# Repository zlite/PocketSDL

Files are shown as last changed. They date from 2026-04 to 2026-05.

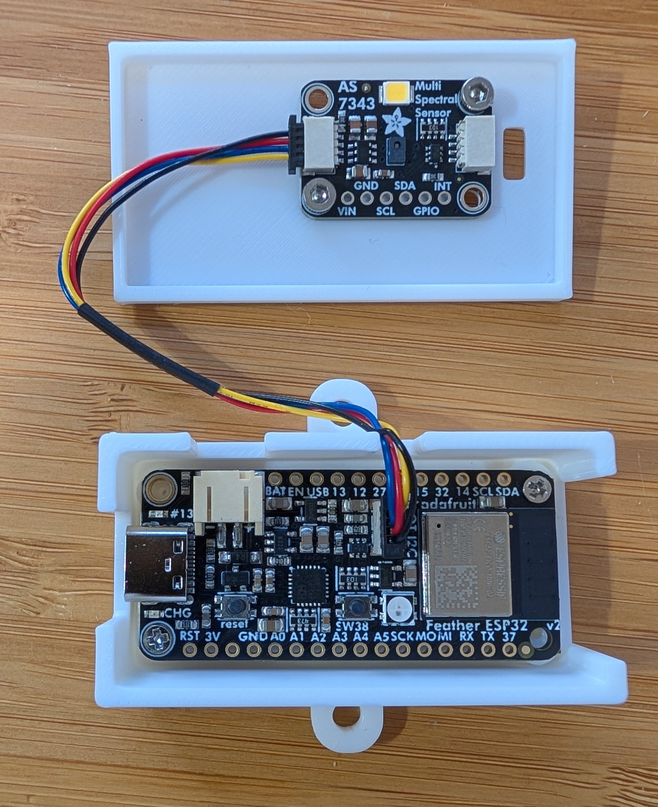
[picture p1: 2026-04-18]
PXL_20260418_005741949.jpg

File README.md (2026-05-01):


This is a minimal self-driving lab demonstration to "discover" color theory by doing an exploration/exploitation search of color space by driving a RGB LED and measuring it with a color sensor, which can be made for $40. Has an optional battery box at the bottom for a 200mah LiPo battery that the Feather can automatically recharge, making this a totally self-contained and portable SDL.

Load code onto ESP32 with the Platormio extension in VSCode (change the port in the ini file to whatever your ESP32 shows up as). Codex or Claude Code extensions in VS Code will do this for you. If you haven't set your wifi details in the code, it will prompt you to enter them on the serial terminal (115200 baud) and then save them so you don't have to do it again. Once it's connected to your network, you should be able to open the UI in your web browser by just typing "sdl.local" in the URL bar. 

If it can't find your network or you haven't given it your network details, after 30 seconds it will switch into AP mode and create its own Wifi network called "SDL" (no password). Just connect to that network with your phone or computer and open a browser and the web interface will just show up automagically.

Alternatively, you can just load the file on the ESP32 using the Arduino IDE.

insides
----
flashing

BOM:
- [Adafruit Feather ESP32 V2](https://www.adafruit.com/product/5400)
- [Adafruit 10-channel color sensor](https://www.adafruit.com/product/4698)

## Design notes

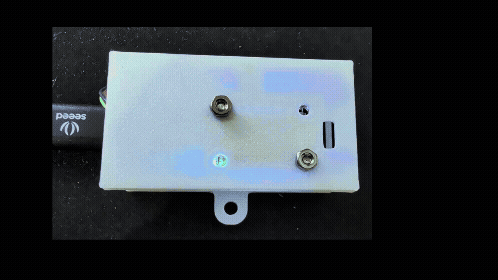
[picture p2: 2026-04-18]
Adobe Express - Video Project.gif

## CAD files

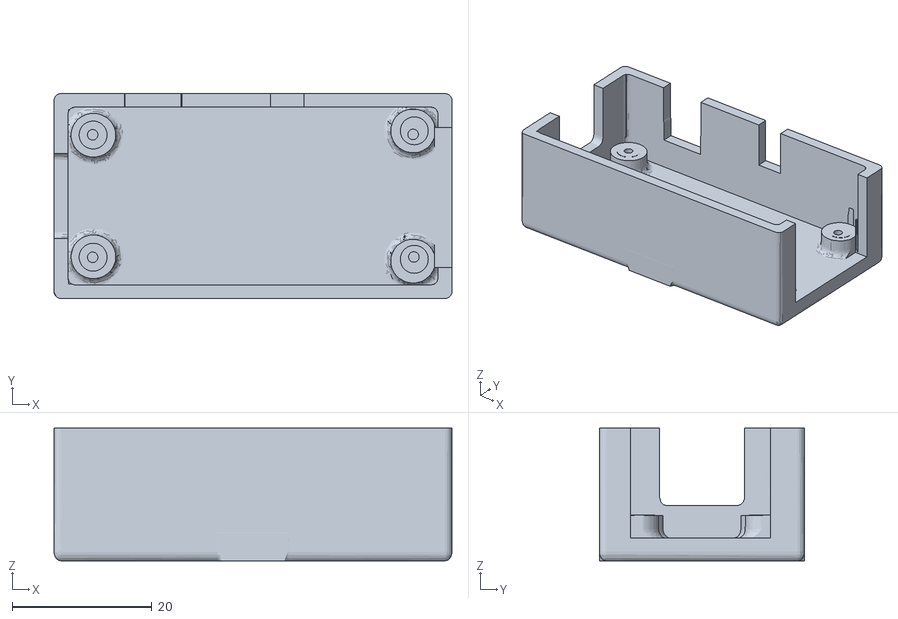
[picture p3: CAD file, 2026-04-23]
base.stl
57.0 x 29.4 x 19.0

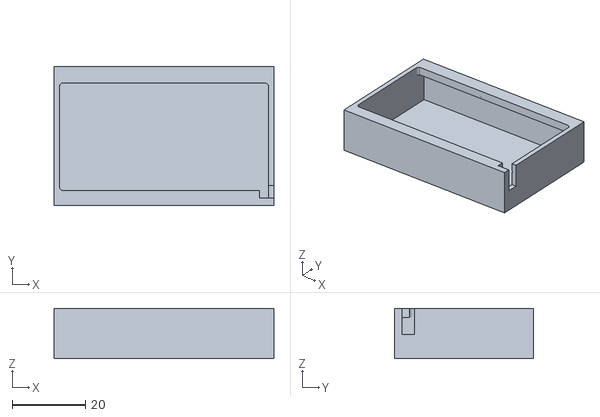
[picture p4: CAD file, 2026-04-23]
batterybox.stl
60.0 x 38.0 x 13.7

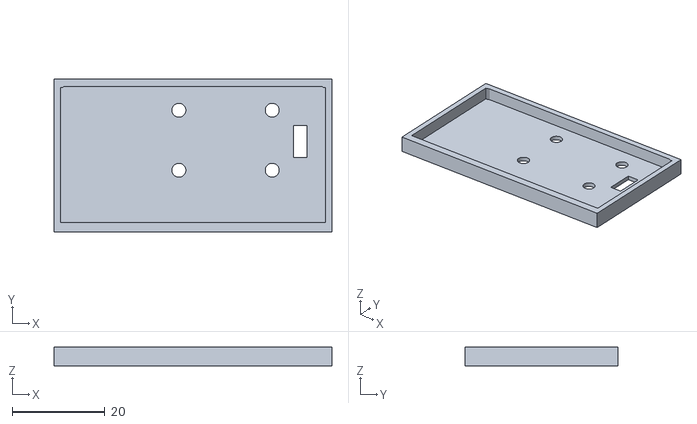
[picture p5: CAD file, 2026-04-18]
cover.stl
60.0 x 33.0 x 4.00

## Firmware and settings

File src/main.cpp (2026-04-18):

#include <Arduino.h>
#include <WiFi.h>
#include <AsyncTCP.h>
#include <ESPAsyncWebServer.h>
#include <ESPmDNS.h>
#include <Wire.h>
#include <math.h>
#include <Preferences.h>
#include <Adafruit_NeoPixel.h>
#include <Adafruit_AS7343.h>

// ── Hardware ──────────────────────────────────────────────────────────────────
#define NEOPIXEL_PIN   0
#define NEOPIXEL_POWER 2
#define LED_BRIGHTNESS 200

#ifndef WIFI_SSID
#define WIFI_SSID "YOUR_WIFI_SSID"
#endif

#ifndef WIFI_PASS
#define WIFI_PASS "YOUR_WIFI_PASSWORD"
#endif

static const char WIFI_SSID_VALUE[] = WIFI_SSID;
static const char WIFI_PASS_VALUE[] = WIFI_PASS;

Adafruit_NeoPixel pixel(1, NEOPIXEL_PIN, NEO_GRB + NEO_KHZ800);
Adafruit_AS7343   as7343;
AsyncWebServer    server(80);
Preferences       prefs;

static uint8_t ledR=0, ledG=0, ledB=0;
static bool    sensorOK=false;
static String  wifiSSID;
static String  wifiPass;

void setLED(uint8_t r, uint8_t g, uint8_t b){
  ledR=r; ledG=g; ledB=b;
  pixel.setPixelColor(0, pixel.Color(r,g,b)); pixel.show();
}

// ── Channel layout (18-ch mode) ───────────────────────────────────────────────
//  0:FZ/450  1:FY/555  2:FXL/600  3:NIR/855  4,5:CLR0
//  6:F2/425  7:F3/475  8:F4/515   9:F6/640   10,11:CLR1
// 12:F1/405 13:F7/690 14:F8/745  15:F5/550   16,17:CLR2
#define NUM_CH 18
static const int   SPEC_CH[] = {12,6,0,7,8,15,1,2,9,13};
static const int   N_SPEC    = 10;
static const float SPEC_WL[] = {405,425,450,475,515,550,555,600,640,690};

// LED spectral weights (Gaussian, R~635nm G~528nm B~455nm)
static const float W_R[NUM_CH]={0.00f,0.11f,0.68f,0.00f,0,0,0.00f,0.00f,0.00f,1.00f,0,0,0.00f,0.39f,0.02f,0.10f,0,0};
static const float W_G[NUM_CH]={0.08f,0.74f,0.12f,0.00f,0,0,0.01f,0.32f,0.93f,0.01f,0,0,0.00f,0.00f,0.00f,0.82f,0,0};
static const float W_B[NUM_CH]={0.98f,0.01f,0.00f,0.00f,0,0,0.49f,0.73f,0.06f,0.00f,0,0,0.14f,0.00f,0.00f,0.01f,0,0};

// ── Buffers ───────────────────────────────────────────────────────────────────
struct Reading { uint8_t r,g,b; uint16_t ch[NUM_CH]; };
static const int LOG_MAX=120; static Reading logBuf[LOG_MAX];
static int logHead=0, logCount=0;

struct Thought { uint8_t r,g,b; float score; bool improved; char msg[96]; };
static const int TH_MAX=50; static Thought thBuf[TH_MAX];
static int thHead=0, thCount=0;

static const int SCORE_MAX=200; static float scoreHist[SCORE_MAX];
static float acceptedScoreHist[SCORE_MAX];
static int scoreHead=0, scoreLen=0;
static int sensorReadFailures=0;

static String jsonEscape(const char* src);
static void setStateMessage(const char* msg);
static void stopExperiment(const char* msg, bool turnLedOff);
static bool hasCompileTimeWiFiCreds();
static bool loadStoredWiFiCreds();
static bool saveStoredWiFiCreds(const String& ssid, const String& pass);
static String readSerialLine(bool echoInput = true);
static bool promptForWiFiCreds();
static void connectWiFi();
static void startMdns();
static bool parseJsonFloat(const String& body, const char* key, float& valueOut);
static String buildStatusJson();
static String buildScoresJson();
static String buildThoughtsJson();
static String buildLogJson();
static String buildSnapshotJson(bool includeLog);
static bool getRequestInt(AsyncWebServerRequest* request, const char* key, int& valueOut);
static bool getRequestFloat(AsyncWebServerRequest* request, const char* key, float& valueOut);
static bool getRequestString(AsyncWebServerRequest* request, const char* key, String& valueOut);
static bool getRequestRgb(AsyncWebServerRequest* request, uint8_t& r, uint8_t& g, uint8_t& b);

void pushScore(float s){
  int idx=scoreHead%SCORE_MAX;
  scoreHist[idx]=s;
  acceptedScoreHist[idx]=-1.0f;
  scoreHead++;
  if(scoreLen<SCORE_MAX)scoreLen++;
}
void pushAcceptedScore(float s){
  int idx=(scoreHead-1+SCORE_MAX)%SCORE_MAX;
  acceptedScoreHist[idx]=s;
}

void addThought(uint8_t r,uint8_t g,uint8_t b,float sc,bool imp,const char* msg){
  Thought& t=thBuf[thHead%TH_MAX]; t.r=r;t.g=g;t.b=b;t.score=sc;t.improved=imp;
  strncpy(t.msg,msg,95); t.msg[95]='\0'; thHead++; if(thCount<TH_MAX)thCount++;
  Serial.printf("[SDL] %s\n",msg);
}

// ── Spectral helpers ──────────────────────────────────────────────────────────
static float recTgtSpec[NUM_CH]={};   // raw target spectrum (sum-normalised in scoring)
static float ambSpec[NUM_CH]={};      // unused — kept for future reference
static uint8_t recTgtR=255, recTgtG=165, recTgtB=0;

static bool isSaturated(const uint16_t* buf){
  for(int i=0;i<N_SPEC;i++) if(buf[SPEC_CH[i]]>60000) return true;
  return false;
}

// Score: 1 - L2 distance between sum-normalised spectra (probability distributions).
// Ambient (dark frame) is subtracted before normalisation so room light doesn't corrupt shape.
// sqrtf(l2) ranges 0 (identical shape) to sqrt(2) (orthogonal), mapped to 0–100%.
float computeScore(const uint16_t* meas){
  if(isSaturated(meas)) return 0.0f;
  float m[N_SPEC], t[N_SPEC];
  float msum=0, tsum=0;
  for(int i=0;i<N_SPEC;i++){
    int ci=SPEC_CH[i];
    m[i]=max(0.0f,(float)meas[ci]-ambSpec[ci]);
    t[i]=recTgtSpec[ci];
    msum+=m[i]; tsum+=t[i];
  }
  if(msum<1.0f||tsum<1.0f) return 0.0f;
  // Luminance penalty: a dim colour that has the right hue shape still scores low.
  // sqrtf keeps it gentle — 50% brightness → 71% penalty, 25% → 50%.
  float lumPenalty = msum < tsum ? sqrtf(msum/tsum) : 1.0f;
  float l2=0;
  for(int i=0;i<N_SPEC;i++){
    float diff=m[i]/msum - t[i]/tsum;
    l2+=diff*diff;
  }
  // Denominator 0.45 calibrated so a random colour averages ~50%; a true match scores ~90%+.
  return max(0.0f,(1.0f - sqrtf(l2)/0.45f)*100.0f) * lumPenalty;
}

void genTargetSpectrum(uint8_t r,uint8_t g,uint8_t b){
  float rf=r/255.0f,gf=g/255.0f,bf=b/255.0f;
  for(int i=0;i<NUM_CH;i++) recTgtSpec[i]=rf*W_R[i]+gf*W_G[i]+bf*W_B[i];
}

// Gaussian random (Box-Muller)
float gaussRand(){
  float u1=max(1e-6f,(float)random(1,1000000)/1000000.0f);
  float u2=(float)random(0,1000000)/1000000.0f;
  return sqrtf(-2.0f*logf(u1))*cosf(2.0f*M_PI*u2);
}

// ── Algorithm state ───────────────────────────────────────────────────────────
enum Alg { ALG_NONE=0, ALG_SPSA, ALG_BAYES, ALG_THOMPSON, ALG_CMAES };
static Alg   alg=ALG_NONE;
static bool  running=false, settling=false;
static uint32_t nextMs=0;
static uint32_t settleMs=200, pauseMs=30;

static float spsaInitH=40.0f, spsaInitA=60.0f;
static int   spsaRestartPatience=40;
static float boKappaInit=3.0f;
static int   boCandidateCount=80;
static float tsBwInit=0.25f;
static int   tsCandidateCount=80;
static float cmaSigmaInit=32.0f;
static int   cmaMuActive=3;

static uint8_t  bestR=128,bestG=128,bestB=128;
static float    bestScore=-1.0f;
static int      totalIter=0;
static int      evalCount=0;
static uint32_t runStartMs=0;
static int32_t  hit90Ms=-1;
static bool     converged=false;
static int      calibPhase=0;  // 0=running, 1=dark reading, 2=target reading
static float    lastScore=0.0f;
static char     stateMsg[100]="Set a target color and press Search.";

static String jsonEscape(const char* src){
  String out;
  if(!src) return out;
  while(*src){
    char c=*src++;
    switch(c){
      case '\\': out+="\\\\"; break;
      case '"':  out+="\\\""; break;
      case '\n': out+="\\n"; break;
      case '\r': out+="\\r"; break;
      case '\t': out+="\\t"; break;
      default:
        if((uint8_t)c >= 0x20) out += c;
        break;
    }
  }
  return out;
}

static void setStateMessage(const char* msg){
  if(!msg){
    stateMsg[0]='\0';
    return;
  }
  strncpy(stateMsg,msg,sizeof(stateMsg)-1);
  stateMsg[sizeof(stateMsg)-1]='\0';
}

static void stopExperiment(const char* msg, bool turnLedOff){
  running=false;
  settling=false;
  calibPhase=0;
  if(msg) setStateMessage(msg);
  if(turnLedOff) setLED(0,0,0);
}

static bool hasCompileTimeWiFiCreds(){
  return strcmp(WIFI_SSID_VALUE,"YOUR_WIFI_SSID")!=0;
}

static bool loadStoredWiFiCreds(){
  if(!prefs.begin("wifi", true)) return false;
  wifiSSID = prefs.getString("ssid", "");
  wifiPass = prefs.getString("pass", "");
  prefs.end();
  return wifiSSID.length() > 0;
}

static bool saveStoredWiFiCreds(const String& ssid, const String& pass){
  if(!prefs.begin("wifi", false)) return false;
  bool ok = prefs.putString("ssid", ssid) > 0;
  prefs.putString("pass", pass);
  prefs.end();
  return ok;
}

static String readSerialLine(bool echoInput){
  String line;
  while(true){
    while(!Serial.available()) delay(10);
    char c = (char)Serial.read();
    if(c == '\r') continue;
    if(c == '\n'){
      if(echoInput) Serial.println();
      break;
    }
    if(c == '\b' || c == 127){
      if(line.length() > 0){
        line.remove(line.length() - 1);
        if(echoInput) Serial.print("\b \b");
      }
      continue;
    }
    if((uint8_t)c < 0x20) continue;
    line += c;
    if(echoInput) Serial.print(c);
  }
  return line;
}

static bool promptForWiFiCreds(){
  Serial.println();
  Serial.println("WiFi credentials not found.");
  Serial.println("Enter them in the serial monitor and press Enter.");
  while(true){
    Serial.print("SSID: ");
    wifiSSID = readSerialLine();
    if(wifiSSID.length() > 0) break;
    Serial.println("SSID cannot be empty.");
  }
  Serial.print("Password (leave blank for open network): ");
  wifiPass = readSerialLine();
  if(!saveStoredWiFiCreds(wifiSSID, wifiPass)){
    Serial.println("WARN: failed to save WiFi credentials to NVS.");
  } else {
    Serial.println("Saved WiFi credentials.");
  }
  return true;
}

static void connectWiFi(){
  if(hasCompileTimeWiFiCreds()){
    wifiSSID = WIFI_SSID_VALUE;
    wifiPass = WIFI_PASS_VALUE;
  } else if(!loadStoredWiFiCreds()){
    promptForWiFiCreds();
  }

  if(wifiSSID.length() == 0){
    Serial.println("WiFi disabled: no credentials available.");
    setStateMessage("WiFi disabled: enter credentials in Serial.");
    return;
  }

  WiFi.begin(wifiSSID.c_str(), wifiPass.c_str());
  Serial.print("Connecting to ");
  Serial.print(wifiSSID);
  Serial.print(" ");
  setLED(0,0,60);
  int tries=0;
  while(WiFi.status()!=WL_CONNECTED&&tries++<40){delay(500);Serial.print(".");}
  if(WiFi.status()==WL_CONNECTED){
    startMdns();
    setLED(0,60,0);delay(1200);setLED(0,0,0);
  } else {
    Serial.println("\nWiFi failed");
    setStateMessage("WiFi connection failed. Reboot to re-enter credentials in Serial.");
    setLED(60,0,0);delay(2000);setLED(0,0,0);
  }
}

static void startMdns(){
  const char* hostName = "sdl";
  if(MDNS.begin(hostName)){
    MDNS.addService("http", "tcp", 80);
    Serial.println("\nOpen: http://" + String(hostName) + ".local or http://" + WiFi.localIP().toString());
    setStateMessage("WiFi connected at http://sdl.local");
  } else {
    Serial.println("\nOpen: http://" + WiFi.localIP().toString());
    Serial.println("WARN: mDNS failed to start; use the IP address instead.");
    setStateMessage("WiFi connected (mDNS unavailable).");
  }
}

void updateBest(uint8_t r,uint8_t g,uint8_t b,float sc,const char* alg_name){
  bool imp=(sc>bestScore);
  if(imp){ bestScore=sc; bestR=r; bestG=g; bestB=b; }
  if(hit90Ms < 0 && imp && bestScore >= 90.0f && runStartMs > 0){
    hit90Ms = (int32_t)(millis() - runStartMs);
  }
  char msg[100];
  snprintf(msg,99,"%s step %d: rgb(%d,%d,%d) score=%.1f%s",
    alg_name,totalIter,r,g,b,sc,imp?" ↑ BETTER":"");
  setStateMessage(msg);
  addThought(r,g,b,sc,imp,msg);
  pushScore(sc);
  pushAcceptedScore(sc);
  totalIter++;
  if(bestScore>95.0f){
    converged=true;
    snprintf(msg,99,"CONVERGED — Recipe: R=%d%% G=%d%% B=%d%% (score=%.1f%%)",
      (int)(bestR/2.55f),(int)(bestG/2.55f),(int)(bestB/2.55f),bestScore);
    setStateMessage(msg);
    addThought(bestR,bestG,bestB,bestScore,true,msg);
    running=false; setLED(bestR,bestG,bestB);
  } else if(evalCount>=400){
    converged=false;
    snprintf(msg,99,"BUDGET REACHED — Recipe: R=%d%% G=%d%% B=%d%% (score=%.1f%%)",
      (int)(bestR/2.55f),(int)(bestG/2.55f),(int)(bestB/2.55f),bestScore);
    setStateMessage(msg);
    addThought(bestR,bestG,bestB,bestScore,false,msg);
    running=false; setLED(bestR,bestG,bestB);
  }
}

void resetAll(){
  logHead=logCount=0; thHead=thCount=0; scoreHead=scoreLen=0;
  bestScore=-1.0f; bestR=bestG=bestB=128; totalIter=0; converged=false;
  evalCount=0;
  runStartMs=0;
  hit90Ms=-1;
  lastScore=0.0f;
  sensorReadFailures=0;
}

// ── Algorithm 1: SPSA Gradient Descent ───────────────────────────────────────
// Simultaneous perturbation — 2 measurements per gradient estimate
static float   spRf=128,spGf=128,spBf=128; // float to accumulate sub-unit steps
static int8_t  spDelta[3]={1,1,1};
static float   spScorePlus=0;
static float   spH=40.0f, spA=60.0f;
static int     spPhase=0, spK=0, spNoImprov=0;

void initSPSA(){
  spRf=random(256); spGf=random(256); spBf=random(256);
  spH=spsaInitH; spA=spsaInitA; spPhase=0; spK=0; spNoImprov=0;
}
// 3 phases per gradient step: probe+, probe-, evaluate updated position
void stepSPSA(){
  if(spPhase==0){
    for(int d=0;d<3;d++) spDelta[d]=(random(2)*2-1);
    setLED((uint8_t)constrain((int)(spRf+spH*spDelta[0]),0,255),
           (uint8_t)constrain((int)(spGf+spH*spDelta[1]),0,255),
           (uint8_t)constrain((int)(spBf+spH*spDelta[2]),0,255));
  } else if(spPhase==1){
    setLED((uint8_t)constrain((int)(spRf-spH*spDelta[0]),0,255),
           (uint8_t)constrain((int)(spGf-spH*spDelta[1]),0,255),
           (uint8_t)constrain((int)(spBf-spH*spDelta[2]),0,255));
  } else { // phase 2: evaluate the actual updated position
    setLED((uint8_t)constrain((int)spRf,0,255),
           (uint8_t)constrain((int)spGf,0,255),
           (uint8_t)constrain((int)spBf,0,255));
  }
}
void afterSPSA(const Reading& rd, float sc){
  if(spPhase==0){ spScorePlus=sc; pushScore(sc); spPhase=1; return; }
  if(spPhase==1){
    float diff=(spScorePlus-sc)/(2.0f*spH);
    float ak=spA/powf(spK+1+10,0.602f);
    spRf=constrain(spRf+ak*diff*(float)spDelta[0],0.0f,255.0f);
    spGf=constrain(spGf+ak*diff*(float)spDelta[1],0.0f,255.0f);
    spBf=constrain(spBf+ak*diff*(float)spDelta[2],0.0f,255.0f);
    spH=max(spH*0.995f,6.0f); spK++;
    pushScore(sc); spPhase=2; return;
  }
  // Phase 2: sc is the score at the updated position
  float prevBest=bestScore;
  updateBest((uint8_t)spRf,(uint8_t)spGf,(uint8_t)spBf,sc,"GD-SPSA");
  if(sc>prevBest+0.5f) spNoImprov=0; else spNoImprov++;
  if(!converged && spNoImprov>spsaRestartPatience){
    // Stuck in local optimum — restart from new random position
    addThought(spRf,spGf,spBf,sc,false,"SPSA stuck, restarting random...");
    spRf=random(256); spGf=random(256); spBf=random(256);
    spH=spsaInitH; spK=0; spNoImprov=0;
  }
  spPhase=0;
}

// ── Algorithm 2: Bayesian Optimisation (IDW-UCB) ──────────────────────────────
static const int BO_MAX=60;
struct BOObs { float r,g,b,score; };
static BOObs   boHist[BO_MAX]; static int boLen=0;
static float   boKappa=3.0f;

void initBO(){
  boLen=0; boKappa=boKappaInit;
  setLED(random(256),random(256),random(256)); // start random
}
float boIDW(float r,float g,float b, float* varOut){
  int nObs=min(boLen,BO_MAX);
  float wsum=0,wmean=0,wvar=0;
  for(int i=0;i<nObs;i++){
    float dr=(r-boHist[i].r)/255.0f, dg=(g-boHist[i].g)/255.0f, db=(b-boHist[i].b)/255.0f;
    float d2=dr*dr+dg*dg+db*db;
    float w=1.0f/(d2+1e-4f);
    wsum+=w; wmean+=w*boHist[i].score;
  }
  if(wsum<1e-9f){ *varOut=50.0f*50.0f; return 50.0f; }
  float mean=wmean/wsum;
  for(int i=0;i<nObs;i++){
    float dr=(r-boHist[i].r)/255.0f, dg=(g-boHist[i].g)/255.0f, db=(b-boHist[i].b)/255.0f;
    float d2=dr*dr+dg*dg+db*db; float w=1.0f/(d2+1e-4f);
    float diff=boHist[i].score-mean; wvar+=w*diff*diff;
  }
  *varOut=wvar/wsum; return mean;
}
void stepBO(){
  if(boLen<2){ setLED(random(256),random(256),random(256)); return; }
  // Sample 80 candidates, pick highest UCB
  uint8_t bR=bestR,bG=bestG,bB=bestB; float bAcq=-1e9;
  for(int k=0;k<boCandidateCount;k++){
    uint8_t cr=random(256),cg=random(256),cb=random(256);
    float v; float m=boIDW(cr,cg,cb,&v);
    float acq=m+boKappa*sqrtf(v);
    if(acq>bAcq){ bAcq=acq; bR=cr; bG=cg; bB=cb; }
  }
  setLED(bR,bG,bB);
}
void afterBO(const Reading& rd, float sc){
  if(boLen<BO_MAX){ boHist[boLen++]={(float)ledR,(float)ledG,(float)ledB,sc}; }
  else { boHist[boLen%BO_MAX]={(float)ledR,(float)ledG,(float)ledB,sc}; boLen++; }
  boKappa=max(boKappa*0.995f,0.5f); // decay exploration
  updateBest(ledR,ledG,ledB,sc,"BO");
}

// ── Algorithm 3: Thompson Sampling ───────────────────────────────────────────
static const int TS_MAX=60;
struct TSObs { float r,g,b,score; };
static TSObs   tsHist[TS_MAX]; static int tsLen=0;
static float   tsBW=0.25f; // kernel bandwidth

void initTS(){ tsLen=0; tsBW=tsBwInit; setLED(random(256),random(256),random(256)); }
void stepTS(){
  if(tsLen<3){ setLED(random(256),random(256),random(256)); return; }
  int nObs=min(tsLen,TS_MAX);
  uint8_t bR=bestR,bG=bestG,bB=bestB; float bSamp=-1e9;
  for(int k=0;k<tsCandidateCount;k++){
    uint8_t cr=random(256),cg=random(256),cb=random(256);
    // Gaussian kernel posterior
    float wsum=0,wmean=0,wvar=0;
    for(int i=0;i<nObs;i++){
      float dr=(cr-tsHist[i].r)/255.0f,dg=(cg-tsHist[i].g)/255.0f,db=(cb-tsHist[i].b)/255.0f;
      float w=expf(-(dr*dr+dg*dg+db*db)/(2.0f*tsBW*tsBW));
      wsum+=w; wmean+=w*tsHist[i].score;
    }
    float mean=(wsum>1e-9f)?wmean/wsum:50.0f;
    for(int i=0;i<nObs;i++){
      float dr=(cr-tsHist[i].r)/255.0f,dg=(cg-tsHist[i].g)/255.0f,db=(cb-tsHist[i].b)/255.0f;
      float w=expf(-(dr*dr+dg*dg+db*db)/(2.0f*tsBW*tsBW));
      float diff=tsHist[i].score-mean; wvar+=w*diff*diff;
    }
    float std=sqrtf((wsum>1e-9f?wvar/wsum:400.0f)+4.0f);
    float samp=mean+gaussRand()*std; // Thompson sample
    if(samp>bSamp){ bSamp=samp; bR=cr; bG=cg; bB=cb; }
  }
  setLED(bR,bG,bB);
}
void afterTS(const Reading& rd, float sc){
  int idx=tsLen<TS_MAX?tsLen:tsLen%TS_MAX;
  tsHist[idx]={(float)ledR,(float)ledG,(float)ledB,sc}; tsLen++;
  tsBW=max(tsBW*0.997f,0.05f);
  updateBest(ledR,ledG,ledB,sc,"TS");
}

// ── Algorithm 4: CMA-ES (diagonal covariance) ─────────────────────────────────
static const int CMA_LAM=6;
static float cmaM[3]={128,128,128};
static float cmaSig=32.0f;
static float cmaSD[3]={1.0f,1.0f,1.0f}; // per-dim scale (diagonal sqrt(C))
static float cmaPS[3]={0,0,0};  // evolution path
static uint8_t cmaOff[CMA_LAM][3]; static float cmaOffSc[CMA_LAM];
static int cmaPhase=0, cmaGen=0;
static const float CMA_CSig=0.3f, CMA_DSig=1.0f;
static const float CMA_CC=0.4f,   CMA_C1=0.2f;

void initCMA(){
  cmaM[0]=random(256); cmaM[1]=random(256); cmaM[2]=random(256); // start random
  cmaSig=cmaSigmaInit; cmaSD[0]=cmaSD[1]=cmaSD[2]=1.0f;
  cmaPS[0]=cmaPS[1]=cmaPS[2]=0; cmaPhase=0; cmaGen=0;
  // Generate first generation
  for(int k=0;k<CMA_LAM;k++)
    for(int d=0;d<3;d++)
      cmaOff[k][d]=(uint8_t)constrain((int)(cmaM[d]+cmaSig*cmaSD[d]*gaussRand()),0,255);
}
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
void loop(){
  if(!running) return;
  if(!sensorOK){
    stopExperiment("Sensor unavailable. Search cannot run.", true);
    return;
  }
  uint32_t now=millis(); if(now<nextMs) return;
  if(!settling){
    if(calibPhase!=0){ settling=true; nextMs=now+settleMs; return; } // wait for calibration
    switch(alg){
      case ALG_SPSA:     stepSPSA();    break;
      case ALG_BAYES:    stepBO();      break;
      case ALG_THOMPSON: stepTS();      break;
      case ALG_CMAES:    stepCMA();     break;
      default: break;
    }
    settling=true; nextMs=now+settleMs;
  } else {
    uint16_t buf[NUM_CH]={};
    if(as7343.readAllChannels(buf)){
      sensorReadFailures=0;
      if(calibPhase==1){
        // Dark frame: LED off — store ambient spectrum then light the target color.
        for(int i=0;i<NUM_CH;i++) ambSpec[i]=(float)buf[i];
        calibPhase=2;
        setLED(recTgtR,recTgtG,recTgtB);
        char msg[100];
        snprintf(msg,sizeof(msg),"Calibrating: reading target rgb(%d,%d,%d)...",recTgtR,recTgtG,recTgtB);
        setStateMessage(msg);
        settling=true; nextMs=now+settleMs;
        return;
      }
      if(calibPhase==2){
        // Target frame: subtract ambient so only LED contribution is stored.
        if(isSaturated(buf)){
          if(currentGainIdx>0){
            currentGainIdx--;
            as7343.setGain((as7343_gain_t)currentGainIdx);
            Serial.printf("Calib saturated, reducing gain to idx=%d\n",currentGainIdx);
            setStateMessage("Calibration saturated, reducing sensor gain...");
            settling=true; nextMs=now+settleMs;
            return;
          }
          stopExperiment("Calibration saturated at minimum gain. Lower LED brightness or move the sensor back.", true);
          return;
        }
        for(int i=0;i<NUM_CH;i++) recTgtSpec[i]=max(0.0f,(float)buf[i]-ambSpec[i]);
        calibPhase=0;
        setStateMessage("Calibrated. Searching from random start...");
        switch(alg){
          case ALG_SPSA:     initSPSA();    break;
          case ALG_BAYES:    initBO();      break;
          case ALG_THOMPSON: initTS();      break;
          case ALG_CMAES:    initCMA();     break;
          default: break;
        }
        settling=false; nextMs=now+pauseMs;
        return;
      }
      int idx=logHead%LOG_MAX;
      Reading& rd=logBuf[idx]; rd.r=ledR;rd.g=ledG;rd.b=ledB;
      memcpy(rd.ch,buf,sizeof(rd.ch)); logHead++; if(logCount<LOG_MAX)logCount++;
      evalCount++;
      float sc=computeScore(buf);
      lastScore=sc;
      switch(alg){
        case ALG_SPSA:     afterSPSA(rd,sc);    break;
        case ALG_BAYES:    afterBO(rd,sc);      break;
        case ALG_THOMPSON: afterTS(rd,sc);      break;
        case ALG_CMAES:    afterCMA(rd,sc);     break;
        default: break;
      }
    } else {
      sensorReadFailures++;
      Serial.printf("WARN: readAllChannels failed (%d)\n",sensorReadFailures);
      if(sensorReadFailures >= 5){
        stopExperiment("Repeated sensor read failures. Check wiring/power and recalibrate.", true);
        return;
      }
    }
    settling=false; nextMs=now+pauseMs;
  }
}

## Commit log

2026-04-18 Update README with web access instructions
    Added instructions for accessing the device via web browser after WiFi connection.
2026-04-23 Enhance README with battery box info and IDE instructions
    Expanded the README to include details about the optional battery box and instructions for using the Arduino IDE.
